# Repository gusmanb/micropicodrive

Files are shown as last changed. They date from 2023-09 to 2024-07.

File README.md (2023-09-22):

# MicroPicoDrive - An internal replacement of the Sinclair QL Microdrive.

## UPDATE 22/03/2023

The device has been tested and patched to work with Minerva. Yup!
Also, the PCB has been modified, it should now be correctly placed but I'm waiting to receive a new batch of PCB's, until then I can't ensure 100% that it is totally fixed.

The Wiki has been set in place with documentation on how to assemble and use the device.

The BOM has been added to the Hardware folder and contains links to the more uncommon components.

Have fun!

# Initial commit

WARNING! This is a work in progress, I need to test it with Minerva ROM and do some adjustments to the PCB, be ware!

So, I got a Sinclair QL some months ago, I wanted one for many many years, I'm a Sinclair fan and I always have been in the Spectrum world and the QL always has been something that I wanted to get.
The unit I got was a broken one, it was stored since the 80's in a repair shop, when I got it the machine was non-working, without microdrives, with a faulty membrane and without a single screw, so the first that I did was to repair it.

And once I got it fully working I wanted to load something, but without microdrives it was a bit difficult... xD

I checked which solutions were available but I didn't liked none so I decided to create my own replacement, armed with my [logic analizer](https://github.com/gusmanb/logicanalyzer) and patience I learnt the internals of the microdrive protocol and created an internal replacement that uses "cartridges" and can be installed in the internal space of the QL.

And this is what I got:




The device is based in an RP2040 (I love the PIO units, those damn things are a wonder!) and some level shifters... and that's it. Well, that's it for the internal unit, there is also a screen, some buttons and an SD card holder for the cartridge!




The thing is completelly working with the stock rom, it can load programs without problems, can format cartridges, store images, etc, all without problems.




Also, I found that a lot of the software is stored as Zip files, the device right now supports MDV, IMG and my own custom format, so I checked the available utilities to manipulate MDV images and... it was a boomer to find that there is no updated one, only mdvtools that is ancient and after compiling manually it I found that most of the converted images were flawed.

So, again, I decided to create mi own solution, and this is what I finally got:

imagen
imagen

It can create MDV images from the ground, import MDV and ZIP files (and yes, it supports the QL zip format, it preserves the executable and data space attributes), manipulate the existing files, extract them, etc, so with this finally I got a full toolset for the QL!

Now I'm waiting for the components to build a 512Kb RAM expansion and from there I don't know where I will continue, may be a floppy drive emulator? IDE interface? Not sure, but the first is to add those 512Kb and a Minerva ROM to test the microdrive.

In any case, this is a work in progress, beware that I need to do some adjustments to the PCB and finish some tools for the software.

If you want more info don't esitate to contact me.

Have fun!

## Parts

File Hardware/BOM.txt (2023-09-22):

--Main unit--

C1 to C6: 100nf, 0603
R1: 4k7, 0603
IC1, IC2: SN74LVC1T45DBVR
IC3: TXU0304PWR
U1: 7805 TO220 or DC/DC buck module
U2: Raspberry pico
J1: Card edge connector, 2x8p, 2.54mm, curved pin.
J2: Male IDC, 2x7p, 2.54mm (check assembly instructions for more details)

--Cartridge--

R1 to R3: 1k, 0603
SW1 to SW3: SMD microswitch push button
SCR1: 0'49" SD1306 module
D1 to D3: 3mm LED (red, green and blue)
SD1: SD card socket module

--Buy links--

SN74LVC1T45:		https://es.aliexpress.com/item/1005004345377244.html
TXU0304PWR:  		https://es.aliexpress.com/item/1005004929752779.html
DC/DC buck converter: 	https://es.aliexpress.com/item/1005005343434991.html
Card edge connector:	https://es.aliexpress.com/item/1005001884522039.html
IDC connector:		https://es.aliexpress.com/item/1005001835803614.html
Screen module:		https://es.aliexpress.com/item/1005003874700775.html
SD card module:		https://es.aliexpress.com/item/32791255542.html

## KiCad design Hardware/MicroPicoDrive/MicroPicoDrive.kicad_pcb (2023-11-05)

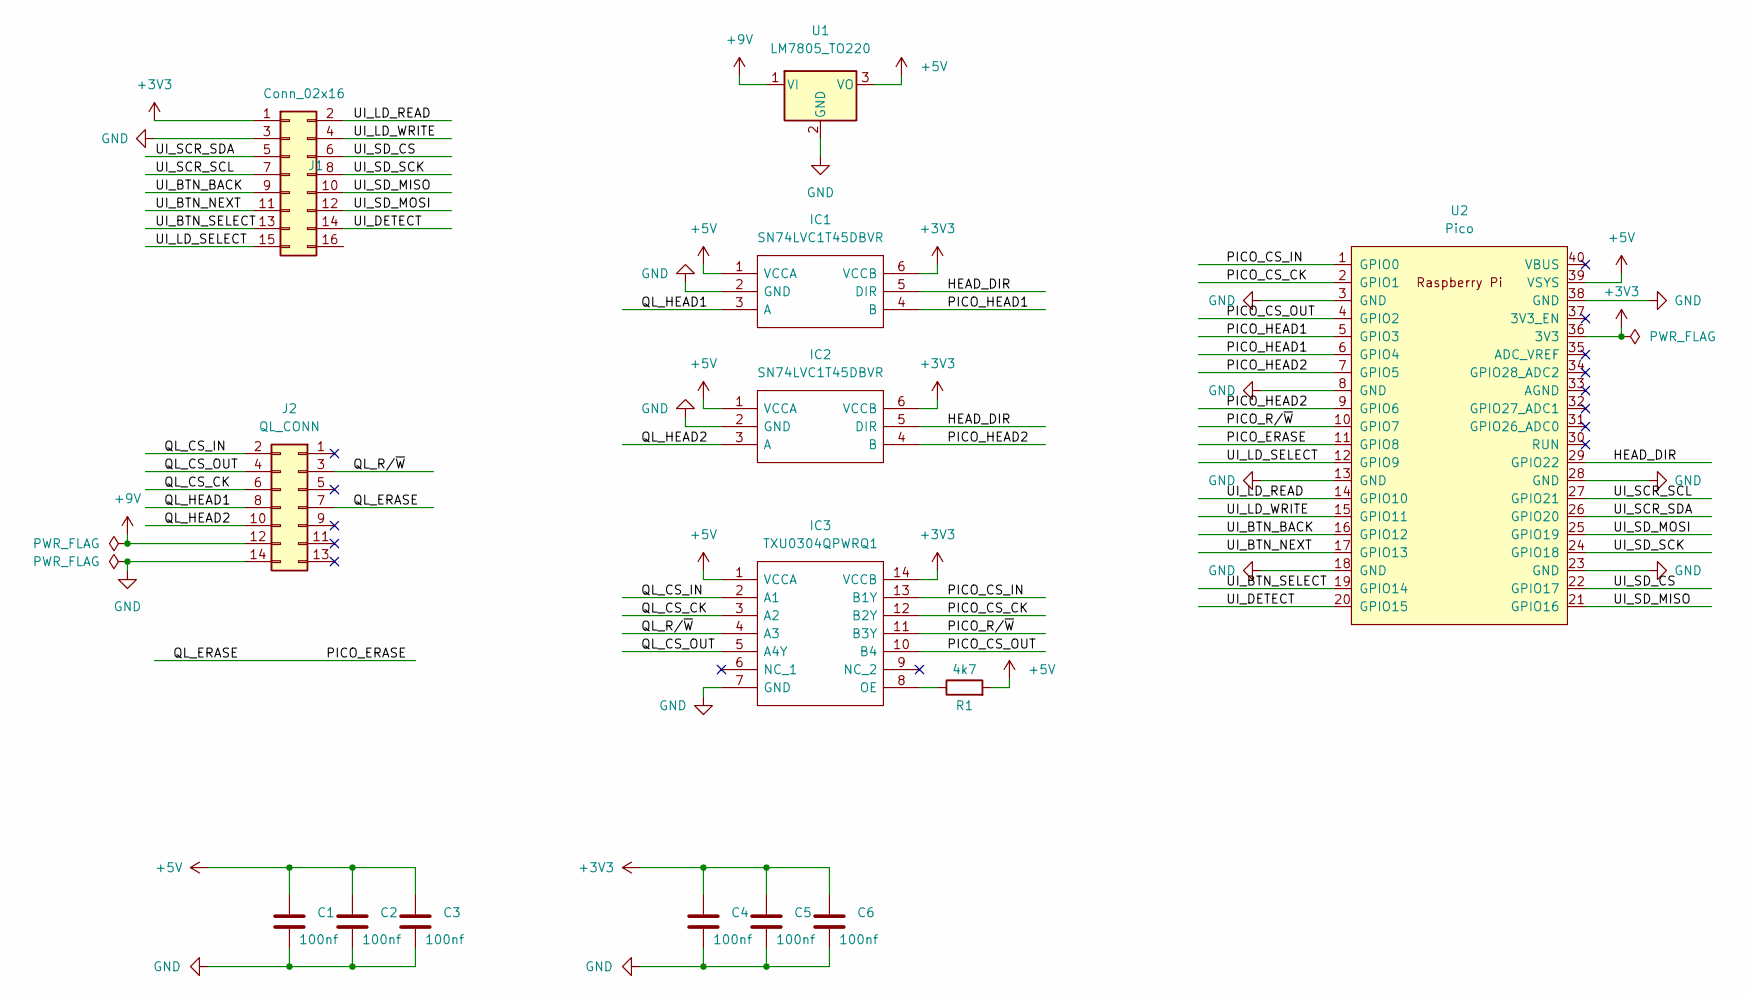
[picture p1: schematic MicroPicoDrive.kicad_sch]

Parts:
C1, C2, C3, C4, C5, C6: 100nf; C_0603_1608Metric
IC1, IC2: SN74LVC1T45DBVR; SOT95P280X145-6N; Mouser Part Number 595-SN74LVC1T45DBVR
IC3: TXU0304QPWRQ1; Mouser Part Number 595-TXU0304QPWRQ1
J1: Conn_02x16; Edge_connector_02x08
J2: QL_CONN; PinHeader_2x07_P2.54mm_Vertical
R1: 4k7; R_0603_1608Metric
U1: LM7805_TO220; TO-220-3_Vertical
U2: Pico; RPi_Pico_SMD_TH

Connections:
+3V3: C4.1, C5.1, C6.1, IC1.6 (VCCB), IC2.6 (VCCB), IC3.14 (VCCB), J1.1, U2.36 (3V3)
+5V: C1.1, C2.1, C3.1, IC1.1 (VCCA), IC2.1 (VCCA), IC3.1 (VCCA), R1.2, U1.3 (VO), U2.39 (VSYS)
+9V: J2.12, U1.1 (VI)
/HEAD_DIR: IC1.5 (DIR), IC2.5 (DIR), U2.29 (GPIO22)
/PICO_CS_CK: IC3.12 (B2Y), U2.2 (GPIO1)
/PICO_CS_IN: IC3.13 (B1Y), U2.1 (GPIO0)
/PICO_CS_OUT: IC3.10 (B4), U2.4 (GPIO2)
/PICO_ERASE: J2.7, U2.11 (GPIO8)
/PICO_HEAD1: IC1.4 (B), U2.5 (GPIO3), U2.6 (GPIO4)
/PICO_HEAD2: IC2.4 (B), U2.7 (GPIO5), U2.9 (GPIO6)
/PICO_R/~W: IC3.11 (B3Y), U2.10 (GPIO7)
/QL_CS_CK: IC3.3 (A2), J2.6
/QL_CS_IN: IC3.2 (A1), J2.2
/QL_CS_OUT: IC3.5 (A4Y), J2.4
/QL_HEAD1: IC1.3 (A), J2.8
/QL_HEAD2: IC2.3 (A), J2.10
/QL_R/~W: IC3.4 (A3), J2.3
/UI_BTN_BACK: J1.9, U2.16 (GPIO12)
/UI_BTN_NEXT: J1.11, U2.17 (GPIO13)
/UI_BTN_SELECT: J1.13, U2.19 (GPIO14)
/UI_DETECT: J1.14, U2.20 (GPIO15)
/UI_LD_READ: J1.2, U2.14 (GPIO10)
/UI_LD_SELECT: J1.15, U2.12 (GPIO9)
/UI_LD_WRITE: J1.4, U2.15 (GPIO11)
/UI_SCR_SCL: J1.7, U2.27 (GPIO21)
/UI_SCR_SDA: J1.5, U2.26 (GPIO20)
/UI_SD_CS: J1.6, U2.22 (GPIO17)
/UI_SD_MISO: J1.10, U2.21 (GPIO16)
/UI_SD_MOSI: J1.12, U2.25 (GPIO19)
/UI_SD_SCK: J1.8, U2.24 (GPIO18)
GND: C1.2, C2.2, C3.2, C4.2, C5.2, C6.2, IC1.2 (GND), IC2.2 (GND), IC3.7 (GND), J1.3, J2.14, U1.2 (GND), U2.3 (GND), U2.8 (GND), U2.13 (GND), U2.18 (GND), U2.23 (GND), U2.28 (GND), U2.38 (GND)
unnamed: IC3.8 (OE), R1.1

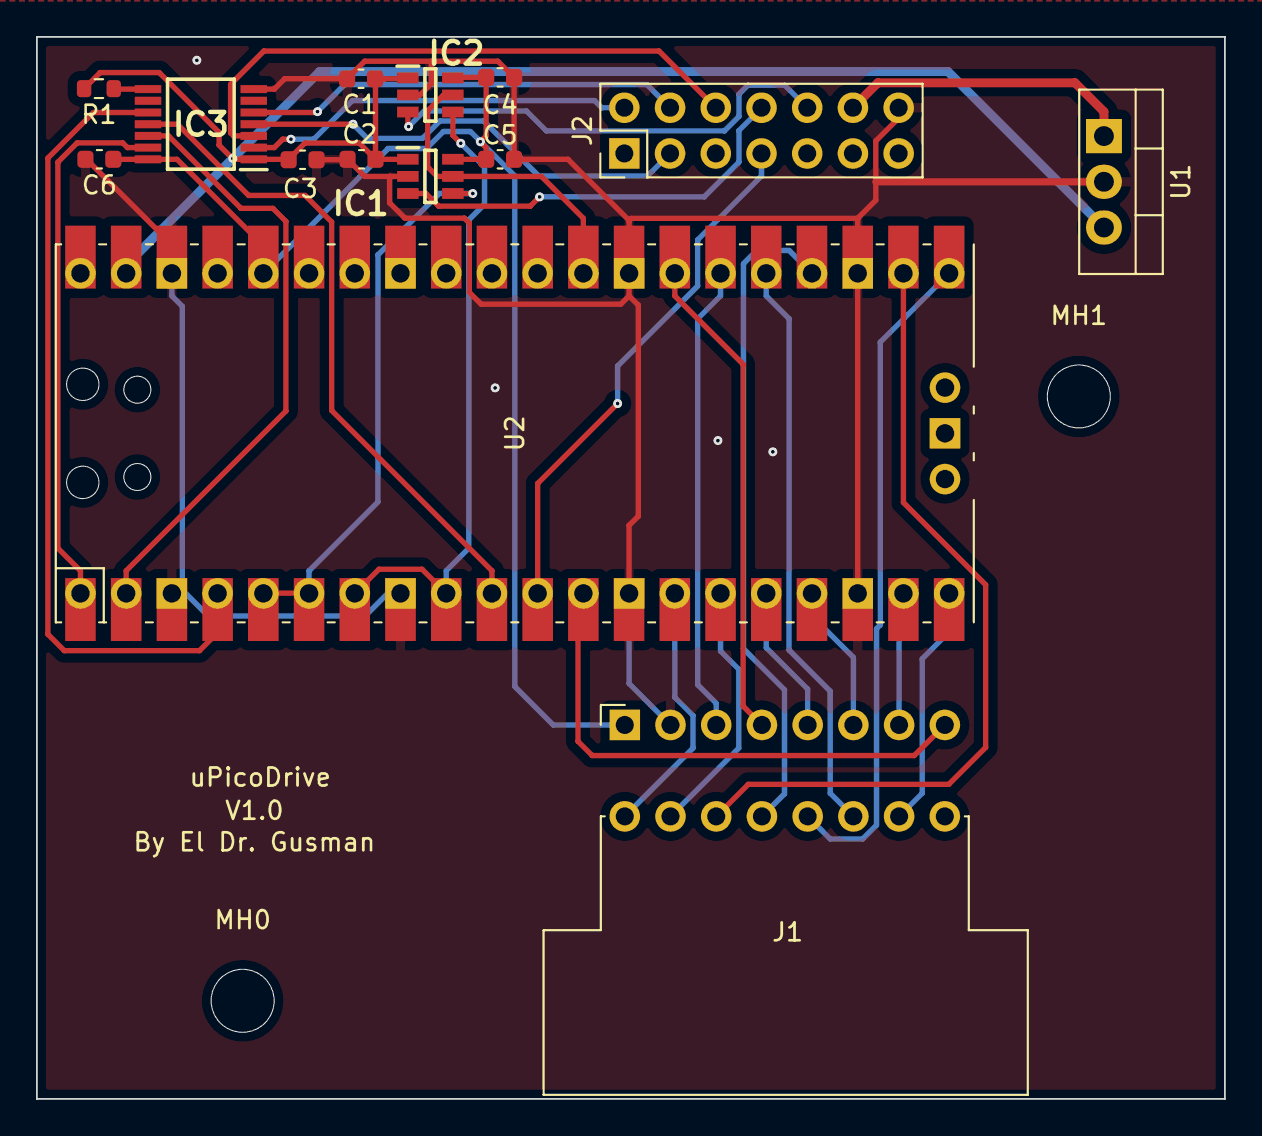
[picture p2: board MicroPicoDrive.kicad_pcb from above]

Board: 2 copper layers, 66.0 x 59.0 mm, 16 parts (0 on the bottom side), 32 nets.

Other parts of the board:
MH0, MH1: MountingHole_3.5mm

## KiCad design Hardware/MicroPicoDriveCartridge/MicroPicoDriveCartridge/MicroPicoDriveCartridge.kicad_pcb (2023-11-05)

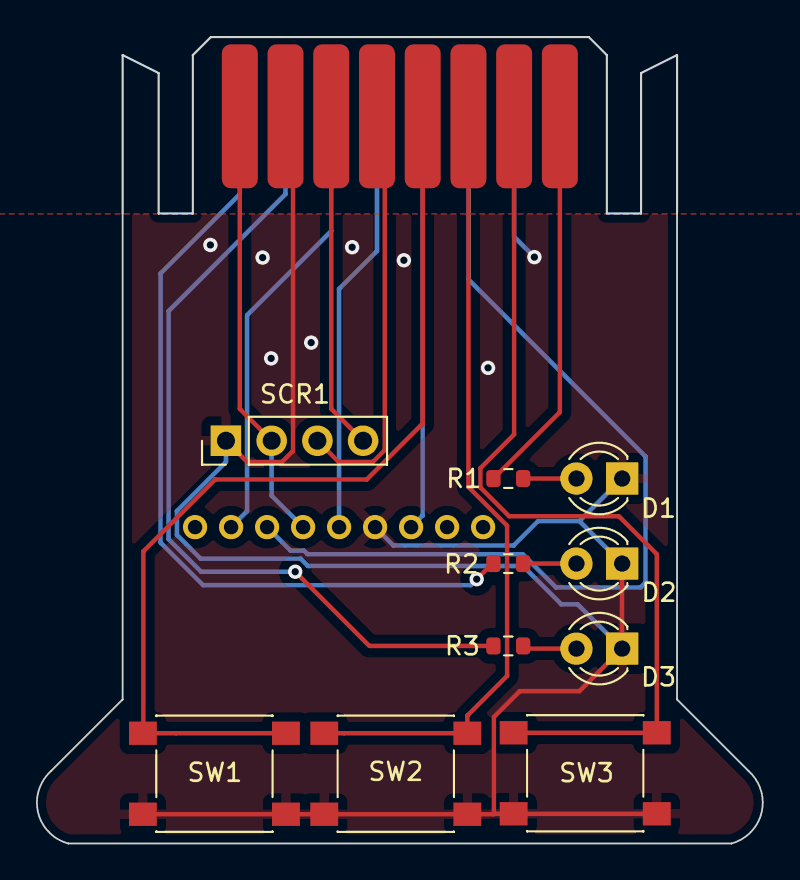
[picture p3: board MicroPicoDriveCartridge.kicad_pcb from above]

Board: 2 copper layers, 40.3 x 44.8 mm, 12 parts (1 on the bottom side), 17 nets.

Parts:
D1, D2, D3: LED; LED_D3.0mm
J1: Conn_02x08_Odd_Even; Edge
R1, R2, R3: 1K; R_0603_1608Metric
SCR1: Screen
SD1: SDCard
SW1, SW2, SW3: SW_Push; SW_Push_1P1T_NO_6x6mm_H9.5mm

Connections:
+3V3: J1.1, SCR1.2 (VCC), SD1.6 (VCC)
/UI_BTN_BACK: J1.9, SW1.1
/UI_BTN_NEXT: J1.11, SW2.1
/UI_BTN_SELECT: J1.13, SW3.1
/UI_LD_READ: J1.2, R2.1
/UI_LD_SELECT: J1.15, R1.1
/UI_LD_WRITE: J1.4, R3.1
/UI_SCR_SCL: J1.7, SCR1.3 (SCL)
/UI_SCR_SDA: J1.5, SCR1.4 (SDA)
/UI_SD_CS: J1.6, SD1.8 (D3/CS)
/UI_SD_MISO: J1.10, SD1.3 (D0/MISO)
/UI_SD_MOSI: J1.12, SD1.7 (CMD/MOSI)
/UI_SD_SCK: J1.8, SD1.5 (CLK)
GND: D1.1 (K), D2.1 (K), D3.1 (K), J1.3, J1.14, SCR1.1 (GND), SD1.4 (GND), SW1.2, SW2.2, SW3.2
unnamed: D1.2 (A), R1.2
unnamed: D2.2 (A), R2.2
unnamed: D3.2 (A), R3.2

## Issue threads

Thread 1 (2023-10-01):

MDVTools

kladogen, 2023-10-01:
Hi, I am working on something similar to your project. I'm trying to understand why you have the following checks in file MicroDriveFile.cs :

    if (currentBlock.Header.SectorNumber != FileMap[0].SectorNumber)
        throw new FileNotFoundException($"Cannot find file sector {FileMap[0].SectorNumber}");

    if (currentBlock.Record.FileBlock != FileMap[0].FileBlock || **currentBlock.Record.FileNumber != FileMap[0].FileNumber**)
        throw new FileNotFoundException($"Cannot find file sector {FileMap[0].SectorNumber}");

and

if (currentBlock.Header.SectorNumber != FileMap[buc].SectorNumber)
    throw new FileNotFoundException($"Cannot find file sector {FileMap[buc].SectorNumber}");

**if (currentBlock.Record.FileBlock != FileMap[buc].FileBlock || currentBlock.Record.FileNumber != FileMap[buc].FileNumber)**
    throw new FileNotFoundException($"Cannot find file sector {FileMap[buc].SectorNumber}");

For some reason the following checks:
*currentBlock.Record.FileNumber != FileMap[0].FileNumber
and
if (currentBlock.Record.FileBlock != FileMap[buc].FileBlock || currentBlock.Record.FileNumber != FileMap[buc].FileNumber)
produce and error for an mdv that works on the QL.

When I remove them it loads the MDV.

Also I tried to export files from various MDV but with no success.

Regards

Antonis

gusmanb, 2023-10-01:
If the check fails then the cartridges are corrupt, in fact I have seen already one cartridge like that and is a cartridge that is copy-protected.

There are two reasons for those checks. The first is on the line before the checks: `var currentBlock = Sectors.Where(s => s.Header.HeaderFlag == 0xFF && s.Header.SectorNumber == FileMap[0].SectorNumber).FirstOrDefault();`

`MicroDriveSector` is a struct, so its default value is not null but an empty struct, to check if it was or was not found I need to compare the result content with what I was searching for, if the sector was not found all will be initialized to zeros and thus the sector number will not match, that explains the first check.

The second reason and second check is to test the integrity of the cartridge. If you are familiar with the format of the microdrive then you know that sector  0 contains a map of sectors with the filenumber/fileblock of each one, and each sector also contains in the record header the filenumber and the fileblock, arguabily if the map does not match what the sector header says then the sector has been corrupted.

Said that, what I have found is that some clever programmers used that as a copy protection: they protected the cartridges by writting those headers without the file/block number, it is set to zero, and it seems the QL ignores that data, it only uses the map at sector zero. If you try to copy the files from one microdrive to another the headers are regenerated and then when the executable runs, checks those headers, if it finds that they are correct then it knows that it has been copied and refuses to run.

As the target of the program is to manipulate cartridge images and when a new image is exported I reconstruct that info like the QL does I do not plan to add support for that particular case.

Finally, about the export, it works but has a "little" bug, the files are always stored in the exec path, it ignores the path you select, only the file name is used. I already have corrected it, it's in the repo, if you pull the changes you will get them.

Cheers.

kladogen, 2023-10-01:
Hi,

To be precise I don't really understand what is happening with:

currentBlock.Record.FileNumber != FileMap[0].FileNumber

The sector map on sector 0 holds a FileNumber and a BlockNumber for sectors 0-254. So If we want to use sector 253 for a file with FileNumber 1 and one block, we need to write at the pair of bytes before the last, the FileNumber (1) and the BlockNumber (0). However in this case, an exception occurs at
currentBlock.Record.FileNumber != FileMap[0].FileNumber
since the file number is 1 but the FileMap[0].FileNumber is 253 and the check fails with a message "Cannot find file sector 253".

If I disable the check, then the next check fails but if I disable that also the MDV loads correctly and shows the files.

Is there something that I have understood mistakenly with sector 0?

Thanks

Antonis

gusmanb, 2023-10-01:
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

Hi.

This is already explained in my previous answer. I'm checking for integrity of the sectors.

This is the microdrive format in a real cartridge:

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

As you can see, after the sector header there is a second header, the block header. This header contains the file number and the block number:

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

What I'm checking there is that what is in the block header matches what is in the sector map. If these don't match then the cartridge image _should_ be corrupted, but there are copy-protected cartridges that intentionally malform that header and the QL seems to not to check that header when reading data:

> Said that, what I have found is that some clever programmers used that as a copy protection: they protected the cartridges by writting those headers without the file/block number, it is set to zero, and it seems the QL ignores that data, it only uses the map at sector zero. If you try to copy the files from one microdrive to another the headers are regenerated and then when the executable runs, checks those headers, if it finds that they are correct then it knows that it has been copied and refuses to run.

If you need more info about the format of the microdrive I recommend you to read the "QL advanced user guide", it contains a full description of the format in appendix D.

Cheers.

kladogen, 2023-10-01:
Hi,

I will check the 253 sector contents then!

Regards,

Antonis

gusmanb, 2023-10-01:
That's not sector 253, FileMap.FileNumber is the first byte of the block header, so that 253 or 0xFD means "empty/damaged sector".

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

kladogen, 2023-10-01:
Thanks, I did not notice that detail for the Header Block in the sector data!

Closed 2024-04-27.

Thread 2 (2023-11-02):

SMD microswitch push button type

Silveriomrs, 2023-11-02:
Hello,
Your BOM doesn't include SMD microswitch push button.
I have some but none of the them match the thumb on the board. Legs are too short

Could you refer the kind of SMD mSwitch that you are using?
Thanks

gusmanb, 2023-11-02:
These are standard 6x6mm SMD microswitches. Here you have an example: https://es.aliexpress.com/item/1005003115135192.html

Silveriomrs, 2023-11-02:
Thank you,
Definitively mine are not the right SMD for it.
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

Closed 2023-11-02.

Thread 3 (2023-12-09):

Botton back doesn't work in some cases.

Silveriomrs, 2023-12-09:
Hi,
Exploring some sub-folder, reaching one empty sub-folder, the system cannot get back from it.

https://github.com/gusmanb/micropicodrive/assets/33696002/de9a0643-b0f7-4508-9eb6-2fc9ccfbf7ee

gusmanb, 2023-12-09:
Will test it once I get a bit of spare time, right now I'm really busy until christmas.

Silveriomrs, 2024-07-07:
Good afternoon!

Just in case my suspects are right... modifying my version of your firmware I got the candidate for the bug.
If you consider to modify yours, that is what I understood.

It join a infinite loop.
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

Thanks

gusmanb, 2024-07-07:
Ok, i have corrected it. Thanks.

Closed 2024-07-07.

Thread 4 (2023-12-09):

Doesn't open some ZIPs

Silveriomrs, 2023-12-09:
Hi again,
Tried to open a MDV inside a ZIP file, it didn't work.
Should I consider something else?
Note: Perhaps I understood wrong the information about what it does and how to use it.

Thanks.

gusmanb, 2023-12-09:
ZIP files aren't supported by the device, uncompress the file before.

Closed 2023-12-09.

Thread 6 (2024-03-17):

the type initializer for "xamarin.tools.zip.native" threw an exception

gferluga, 2024-03-17:
When I try to open a ZIP file I'm getting this error message.

the type initializer for "xamarin.tools.zip.native" threw an exception

I'm running Windows 11 on a Silicon M2 MacBook:

Device name	W11Arm
Processor	Apple Part 000 r0p0   2.00 GHz
Installed RAM	4.00 GB
System type	64-bit operating system, ARM-based processor
Pen and touch	No pen or touch input is available for this display

Edition	Windows 11 Pro
Version	23H2
Installed on	‎03/‎03/‎2024
OS build	22631.3235
Experience	Windows Feature Experience Pack 1000.22687.1000.0

Any idea? Thanks in advance...

gusmanb, 2024-03-17:
Which version are you using? The compiled ones are only for x64, no ARM support. If you're compiling the code by yourself then I would recommend to run it in debug mode as the error should give you more information.

gusmanb, 2024-03-17:
Sorry, can't help there, I have no ARM windows machines but I doubt it would work properly, linked libraries like the Zip one are x64 binaries and Windows in ARM uses an emulation layer to try to run native x64 apps and it's prone to fail.

Closed 2024-04-27.

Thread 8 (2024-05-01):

The type initializer for "xamarin.tools.zip.native" threw an exception (Interl i9)

gferluga, 2024-05-01:
Hello, again...
This time the same issue "The type initializer for "xamarin.tools.zip.native" threw an exception" but on Intel i9 processor on Windows 11 on brand new HP Zbook machine.
Thanks...

gusmanb, 2024-05-01:
Hi.

It seems that W11 + ZipLibSharp + Single File packaging screws up things.

Can you try this version?

[win-x64.zip](https://github.com/gusmanb/micropicodrive/files/15179366/win-x64.zip)

gferluga, 2024-05-01:
Yes. It's working. Thanks!

gferluga, 2024-05-01:
I'll try later on ARM Silicon Mac ;)-

gferluga, 2024-05-04:
I confirm it's working on Windows 11 Arm from VmWare Fusion 17 on MacBook Silicon Arm M2. Hurray!!!

Closed 2024-11-07.

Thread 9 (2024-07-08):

Not an issue by now but function capped out

Silveriomrs, 2024-07-08:
Good afternoon,

Sorry for bothering you again.
Checking some part of the code, in this case managing the DMA control. I've found an conflict of functions ( I have not enough level to evaluate the consequences yet).

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

How the conditions are enums, and the comparing between the 2 terms are separated by ORs, it will be always True.
The Ifs also are linked so the if-else will never happen. In the case it happens... will be always true too due to the same reason, the OR makes it always bigger or smaller than the reference.

Sorry if I don't explain myself properly.

Thank you.

gusmanb, 2024-07-08:
Yes, it's a typo. it should be like this:

```//Abort the DMA's if they were active
    if(activeStatus >= MDA_READ_HEADER_GAP && activeStatus <= MDA_READ_SECTOR)
        disable_DMAs(true);
    else if(activeStatus >= MDA_WRITE_HEADER_GAP && activeStatus <= MDA_WRITE_SECTOR)
        disable_DMAs(false);```

Can you update it in your branch and check if it works properly? if it works I will update the source, right now I'm really busy with my work and don't have time to do a proper testing.

In theory the error will not affect the device as it only stops the DMA's while they aren't used, it is mostly for sanity.

Silveriomrs, 2024-07-08:
I'll do it tonight.
Just I wrote it here cause I can't determinate side effects farther than to check if it continues working as "usual" or not. ASAP I'm going to tell you how it goes.

But till tomorrow I won't be able to try it out connected to a QL, only the browsing powered it by USB.

See you later then with news.

Silveriomrs, 2024-07-08:
Good evening,
It seems to work fine while I browse the SD and load something. Saving feature looks also working but I cannot check it out till tomorrow or later.

> In theory the error will not affect the device as it only stops the DMA's while they aren't used, it is mostly for sanity.

About it, considering the code order, once that function was called, the DMA remained disabled till a new reset or power the device.

Tomorrow I'm going to do more tests connected to my QL.

Keep in mind that I have modified a part of the original code. Not that part (MicroDriveControl), but always there is the possibility that could/couldn't work for me and for yours be fine/wrong.

Could you tell me when that function is called? I mean deselect_md(), that way I could try to force the test oriented to detect problems with it.

Tomorrow more news.

gusmanb, 2024-07-08:
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

Well, you are totally wrong :)

If DMA's were not used, the device would not work at all, it would be a very nice brick. DMAs are automatically rearmed whenever there is any operation and disarmed when a transfer is finalized, so as I stated that code is there only for sanity, is not critical at all.

Do not consider "code order", that's nonsensic, you need to follow the code execution paths, and in this case is very easy as the implementation is basically a bunch of state machines.

The function is executed when... the microdrive is deselected :D
Read from MD1, read from MD2 and go back and forth, each time you change from one drive to the other the one what was active is deselected.

gusmanb, 2024-07-12:
I'm going to close the issue as the patch works correctly.

Closed 2024-07-12.

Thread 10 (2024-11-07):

File corruption

Jobd0ne, 2024-11-07:
I have compiled the new changes you made , which are not on the releases page (it still shows from 2023) a few files start to give read errors and won't run. I'm also getting this issue with popopo's version. I am using an original PCB. when reverting to the original compiled file on here (compiled in 2023 , so cannot have the changes made 4 months ago, no issues.

Jobd0ne, 2024-11-08:
[blank.mdv.zip](https://github.com/user-attachments/files/17674577/blank.mdv.zip)
[MicroPicoDrive.uf2.zip](https://github.com/user-attachments/files/17674584/MicroPicoDrive.uf2.zip)
 Here is one of the offending microdrive images, with the compiled image on github, this works fine (pics to come) but when I compile the newer code from github, this mdv fails. I loaded the newer firmware on mdv2_ and the older on mdv1_  both with the same MDV file from above, and mdv2_ failed, mdv1_ had no issues

Jobd0ne, 2024-11-08:
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

Jobd0ne, 2024-11-08:
the bad name error on mdv1_ is not related, it's because it's trying to call TK2_EXT and it's not installed

Silveriomrs, 2024-12-17:
Jobd0ne, thank you for reporting it.

Your image has a different size.
The firmware tries to recognize the format by its size. Thus your image is not an standard one and is ignore by my firmware.

Anyway that is a blank file as I have tried it out in QEmulator.
From my firmware, it ignores directly non standard size (as I said). In order to keep same philosophy than the original one. So I guess that happen after the second change of the Firmware you mean  from this repo, so hereby mine too that I cloned as base for my modifications.

But thinking about to change it.
Bad  or changed medium... what a pain :) I have been working around it last 3 weeks and solved partially.
I need to go deeper in other part of the software that I didn't yet.

So I would apreciate if you contact me directly and helps to try some changes that I Am working on.

Ah! also same image that you shows in the photos but not a blank cartridge.
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

Silveriomrs, 2024-12-18:
> Apologies, wrong image uploaded, now edited the post

Hi,
It loads fine :) in both. QEmulator and in my QL with MDPs.

I have noticed the QDOS header, but it doesn't bother at all :) it loads fine. Also I see that now you have use the MDV size compatible.

So, is all clear and OK for you?
Please do not hesitate to contact me if you have another issue. Thanks to your reports I am enjoying and learning more and more.

So you may contact me directly in Facebook group or Telegram.
Happy to help

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

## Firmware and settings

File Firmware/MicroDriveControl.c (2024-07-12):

#include "hardware/pio.h"
#include "hardware/gpio.h"
#include "hardware/irq.h"
#include "hardware/dma.h"
#include "hardware/timer.h"
#include "MicroDriveControl.h"
#include "SharedBuffers.h"
#include "SharedEvents.h"
#include "EventMachine.h"
#include "PIO_machines.pio.h"

bool isCartridgeInserted = false;
bool secondBufferSet = false;

mdstatus_t mdStatus = MDS_DESELECTED;
mdactivestatus_t activeStatus = MDA_IDLE;

evtmachine_t mdEventQueue;

uint track1DMA;
uint track2DMA;

bool track1DMAFired = false;
bool track2DMAFired = false;

dma_channel_config track1ReadConfig;
dma_channel_config track2ReadConfig;

dma_channel_config track1WriteConfig;
dma_channel_config track2WriteConfig;

dma_channel_config track1DisabledConfig;
dma_channel_config track2DisabledConfig;

uint rxProgramOffset;
uint statProgramOffset;
uint txProgramOffset;
uint shiftProgramOffset;

int sm_read_head_1;
int sm_read_head_2;
int sm_status;
int sm_exec_read;

int sm_write_head_1;
int sm_write_head_2;
int sm_shifter;
int sm_exec_write;

//enable the microdrive
void select_md()
{
    //Change the md status to active
    mdStatus = MDS_SELECTED;

    //Enable the status machine
    select_PIO_status();

    //Notify to the UI
    mtuevent_t evt;
    evt.event = MTU_MD_SELECTED;
    event_push(&mdToUiEventQueue, &evt);
}

//disable the microdrive
void deselect_md()
{
    //Reset the select status
    mdStatus = MDS_DESELECTED;

    //We store the previous state to check if we need to notify the UI about any buffer change
    mdactivestatus_t previousState = activeStatus;

    //We reset the active status, this may cause the last buffer that was being read or written
    //to be sent again to the ULA if it was a header, but this should not cause any trouble as the QL
    //does not deselect the drive while it's doing a write/format operation
    activeStatus = MDA_IDLE;

    //Abort the alarms if pending
    abort_shifter_alarm();
    abort_write_gap_alarm();

    //Ensure both transfer machines are idle
    sleep_PIO_write();
    begin_PIO_read_gap();

    //Disable the status machine
    deselect_PIO_status();
    
    //Disable the DMAs if they're active
    if(activeStatus >= MDA_READ_HEADER_GAP && activeStatus <= MDA_READ_SECTOR)
        disable_DMAs(true);
    else if(activeStatus >= MDA_WRITE_HEADER_GAP && activeStatus <= MDA_WRITE_SECTOR)
        disable_DMAs(false);

    //Set dir to input to avoid problems
    gpio_put(MD_HEAD_DIR, 1);

    //Check for any buffer change. This is mostly by sanity, the MD should not deselect the device while it's
    //writting to the md and if we send again the same sector to the ULA it will skip it if needed
    check_ui_notifications(previousState, false);

    //Notify to the UI about the device deselection
    mtuevent_t evt;
    evt.event = MTU_MD_DESELECTED;
    event_push(&mdToUiEventQueue, &evt);
}

//This function checks if the UI needs to be notified about any buffer change event
//This is called at the beginning of the gaps and when the device is deselected
void check_ui_notifications(mdactivestatus_t previousState, bool fromGap)
{
    switch(previousState)
    {
        case MDA_READ_SECTOR:   //We were reading a sector from the ULA, notify the UI that it needs to write the buffers to the cartridge
                                //image and fill the buffers with the next sector
        {
            mtuevent_t readEvt;
            readEvt.event = MTU_BUFFERSET_WRITTEN;
            //If we are called from a gap routine the buffer set has already been changed
            //but if we are being called from the deselection method then the bufferset has not been changed.
            if(fromGap)
                readEvt.arg = secondBufferSet ? 0 : 1;
            else
                readEvt.arg = secondBufferSet ? 1 : 0;

            event_push(&mdToUiEventQueue, &readEvt);
        }
            break;

        case MDA_WRITE_SECTOR:  //We were writting a sector to the ULA, notify the UI that it needs to fill the buffers with the next sector
        {
            mtuevent_t writeEvt;
            writeEvt.event = MTU_BUFFERSET_READ;
            //If we are called from a gap routine the buffer set has already been changed
            //but if we are being called from the deselection method then the bufferset has not been changed.
            if(fromGap)
                writeEvt.arg = secondBufferSet ? 0 : 1;
            else
                writeEvt.arg = secondBufferSet ? 1 : 0;

            event_push(&mdToUiEventQueue, &writeEvt);
        }

            break;

    }

    switch(activeStatus)
    {
        case MDA_READ_HEADER_GAP:
        case MDA_READ_SECTOR_GAP:
        {
            mtuevent_t readEvt;
            readEvt.event = MTU_MD_READING;
            event_push(&mdToUiEventQueue, &readEvt);
        }
            break;

        case MDA_WRITE_HEADER_GAP:
        case MDA_WRITE_SECTOR_GAP:
        {
            mtuevent_t writeEvt;
            writeEvt.event = MTU_MD_WRITTING;
            event_push(&mdToUiEventQueue, &writeEvt);
        }
            break;
    }
}
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

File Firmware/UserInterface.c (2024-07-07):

#include <string.h>
#include <stdio.h>
#include "hardware/spi.h"
#include "hardware/gpio.h"
#include "EventMachine.h"
#include "UserInterface.h"
#include "SharedBuffers.h"
#include "SharedEvents.h"
#include "ssd1306/ssd1306.h"
#include "pff/pff.h"

#define LED_ON(LED) gpio_put(LED, true)
#define LED_OFF(LED) gpio_put(LED, false)
#define IS_UI_DISCONNECTED() gpio_get(PIN_UI_DETECT)
#define IN_FOLDER (fno.fattrib & AM_DIR)
#define BUTTON_PRESSED(BUTTON) (!gpio_get(BUTTON))

#define PRINT_STR(STR, COL, ROW) ssd1306_draw_string(&disp, COL * 5, ROW * 8, 1, STR)
#define RENDER_SCREEN() ssd1306_show(&disp)
#define CLEAR_SCREEN() ssd1306_clear(&disp)
#define CONCAT(DEST, SOURCE) sprintf(&DEST[strlen(DEST)],"/%s", SOURCE)
USER_INTERFACE_STATE uiState = IDLE;

ssd1306_t disp;
FATFS fatfs;
DIR dir;
FILINFO fno;
char currentPath[PATH_BUFFER_SIZE];
char lineBuffer[12];
uint8_t currentSector = 0;

bool mdInUse = false;
bool firstFolderEntry = false;

CARTRIDGE_FORMAT cfInserted = NONE;

uint64_t delayEnd;
USER_INTERFACE_STATE uiNextState;

//Writes a pair of buffers of a buffer set (a buffer set are four buffers, two header ones and two sector ones)
void write_buffer_set_pair(uint8_t* source, uint8_t* track1Buffer, uint8_t* track2Buffer, bool isHeader)
{
    track2Buffer += 4; //we skip four bits on buffer 2 to respect the skewing done by the ULA

    for(int buc = 0; buc < PREAMBLE_ZERO_BITS; buc++)
    {
        track1Buffer[buc] = 0;
        track2Buffer[buc] = 0;
    } 

    track1Buffer += PREAMBLE_ZERO_BITS;
    track2Buffer += PREAMBLE_ZERO_BITS;

    for(int buc = 0; buc < PREAMBLE_ONE_BITS; buc++)
    {
        track1Buffer[buc] = 1;
        track2Buffer[buc] = 1;
    } 

    track1Buffer += PREAMBLE_ONE_BITS;
    track2Buffer += PREAMBLE_ONE_BITS;

    uint16_t copySize = isHeader ? HEADER_TRACK_DATA_SIZE : SECTOR_TRACK_DATA_SIZE;

    for(int buc = 0; buc < copySize; buc++)
    {
        uint8_t t1b = *source;
        source++;
        uint8_t t2b = *source;
        source++;

        for(int buc = 0; buc < 8; buc++)
        {
            *track1Buffer = (t1b >> buc) & 1;
            *track2Buffer = (t2b >> buc) & 1;
            track1Buffer++;
            track2Buffer++;
        }
    }
}

//Writes a buffer set with cartridge data
void write_buffer_set(uint8_t setNumber, uint8_t sector)
{
    if(setNumber == 0)
    {
        write_buffer_set_pair(&cartridge_image[CARTRIDGE_SECTOR_SIZE * sector], header_1_track_1, header_1_track_2, true);
        write_buffer_set_pair(&cartridge_image[CARTRIDGE_SECTOR_SIZE * sector + CARTRIDGE_HEADER_SIZE], sector_1_track_1, sector_1_track_2, false);
        bufferset_1_sector_number = sector;
    }
    else
    {
        write_buffer_set_pair(&cartridge_image[CARTRIDGE_SECTOR_SIZE * sector], header_2_track_1, header_2_track_2, true);
        write_buffer_set_pair(&cartridge_image[CARTRIDGE_SECTOR_SIZE * sector + CARTRIDGE_HEADER_SIZE], sector_2_track_1, sector_2_track_2, false);
        bufferset_2_sector_number = sector;
    }
}

//Find the end of a preamble from a track buffer
int8_t find_preamble_end(uint8_t* buffer)
{
    uint8_t zeroCount = 0;
    uint8_t oneCount = 0;

    //We need to find at least 16 zeros followed by 8 ones (0x00, 0x00, 0xFF)
    for(int buc = 0; buc < 100; buc++)
    {
        if(buffer[buc] == 0)
        {
            if(oneCount != 0) //Do we came here form a one?
            {
                //Reset everything
                zeroCount = 1;
                oneCount = 0;
            }
            else
                zeroCount++; //Increment count

        }
        else
        {
            if(zeroCount < 16) //Did we found a one before having eight zeros?
            {
                //Reset everything
                oneCount = 0;
                zeroCount = 0;
            }
            else
                oneCount++; //Increment count
        }

        //Have we found the eight ones?
        if(oneCount == 8)
            return buc + 1;
    }

    //Error! We haven't found the gap end!!
    return -1;

}

bool inFormat = false;
int skip = 0;

//Reads a pair of buffers from a buffer set (a buffer set are four buffers, two header ones and two sector ones)
void read_buffer_set_pair(uint8_t* destination, uint8_t* track1Buffer, uint8_t* track2Buffer, bool isHeader)
{
    uint16_t track1Pos = find_preamble_end(track1Buffer);
    uint16_t track2Pos = find_preamble_end(track2Buffer);

    uint16_t size = isHeader ? HEADER_TRACK_DATA_SIZE : SECTOR_TRACK_DATA_SIZE;

    //Check if we're writting sector 255, if true then this is a format
    if(isHeader && !inFormat)
    {
        uint8_t sectorNumber = track2Buffer[track2Pos] |
            track2Buffer[track2Pos + 1] << 1 |
            track2Buffer[track2Pos + 2] << 2 |
            track2Buffer[track2Pos + 3] << 3 |
            track2Buffer[track2Pos + 4] << 4 |
            track2Buffer[track2Pos + 5] << 5 |
            track2Buffer[track2Pos + 6] << 6 |
            track2Buffer[track2Pos + 7] << 7;

        if(sectorNumber == 255)
        {
            inFormat = 1;
            skip = currentSector;
        }
    }

    for(uint16_t buc = 0; buc < size; buc++)
    {
        *destination = track1Buffer[track1Pos] |
            track1Buffer[track1Pos + 1] << 1 |
            track1Buffer[track1Pos + 2] << 2 |
            track1Buffer[track1Pos + 3] << 3 |
            track1Buffer[track1Pos + 4] << 4 |
            track1Buffer[track1Pos + 5] << 5 |
            track1Buffer[track1Pos + 6] << 6 |
            track1Buffer[track1Pos + 7] << 7;

        track1Pos += 8;
        destination++;

        *destination = track2Buffer[track2Pos] |
            track2Buffer[track2Pos + 1] << 1 |
            track2Buffer[track2Pos + 2] << 2 |
            track2Buffer[track2Pos + 3] << 3 |
            track2Buffer[track2Pos + 4] << 4 |
            track2Buffer[track2Pos + 5] << 5 |
            track2Buffer[track2Pos + 6] << 6 |
            track2Buffer[track2Pos + 7] << 7;

        track2Pos += 8;
        destination++;

    }
}

//Reads a buffer set to the cartridge buffer
void read_buffer_set(uint8_t setNumber)
{
    if(setNumber == 0)
    {
        read_buffer_set_pair(&cartridge_image[CARTRIDGE_SECTOR_SIZE * bufferset_1_sector_number], header_1_track_1, header_1_track_2, true);
        read_buffer_set_pair(&cartridge_image[CARTRIDGE_SECTOR_SIZE * bufferset_1_sector_number + CARTRIDGE_HEADER_SIZE], sector_1_track_1, sector_1_track_2, false);
    }
    else
    {
        read_buffer_set_pair(&cartridge_image[CARTRIDGE_SECTOR_SIZE * bufferset_2_sector_number], header_2_track_1, header_2_track_2, true);
        read_buffer_set_pair(&cartridge_image[CARTRIDGE_SECTOR_SIZE * bufferset_2_sector_number + CARTRIDGE_HEADER_SIZE], sector_2_track_1, sector_2_track_2, false);
    }
}
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

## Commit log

2023-09-22 Updated PCB, added BOM and links, updated MDToolsUI
    [MicroPicoDrive.kicad_pcb]
2023-09-22 Removed fabrication outputs from KiCad projects
    [MicroPicoDrive-B_Cu.gbl, MicroPicoDrive-B_Mask.gbs, MicroPicoDrive-B_Paste.gbp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]
2023-11-05 Updated PCBs
    [MicroPicoDrive.kicad_pcb, MicroPicoDriveCartridge.kicad_pcb]
2024-07-12 Update MicroDriveControl.c
    Corrected DMA cancellation in drive deselection
    [MicroDriveControl.c]
